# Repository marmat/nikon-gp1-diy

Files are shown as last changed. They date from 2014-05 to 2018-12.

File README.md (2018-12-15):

DIY GPS Module for Nikon DSLRs
==============================

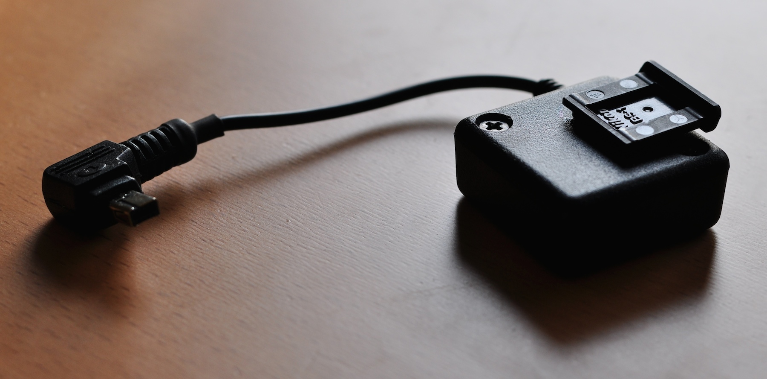
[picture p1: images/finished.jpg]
The finished device


Using a GPS Module, most modern Nikon DSLRs are able to automatically geotag
pictures right when taking them. Unfortunately, the official Nikon GP-1 is very
expensive (~200€). This project contains all necessary information to create a
low-cost module which works just as well. This DIY version costs around 30€
(40$).

- [Requirements](#requirements)
  - [Tools](#tools)
  - [Parts](#parts)
  - [Electronic Components](#electronic-components)
- [Building Instructions](#building-instructions)
- [Technical Details](#technical-details)
  - [Nikon GPS Port Specs](#nikon-gps-port-specs)
  - [Protocol](#protocol)
  - [Schematics](#schematics)
- [Images](#images)
- [Sources](#sources)

See also the [Building Log](BUILD.md).

Requirements
------------

### Tools

- Soldering Equipment
- Sharp knife to cut soft plastic
- A small dremel or similar to cut hard plastic
- Plastic Glue
- Screwdriver

### Parts

| Item | Description |
| --- | --- |
| Case | Hammond 1551NBK |
| PCB | Board layout available in [eagle](eagle/) folder. Either create your own if you have the equipment, visit your local [FabLab](http://en.wikipedia.org/wiki/Fablab) or let the PCB be created professionally (look for cheap companies in your region). |
| Cable & Connector | Can be taken from a cheap remote cable trigger. |

### Electronic Components

|  ID |  Item description | Part No. |  Size |
| --- | --- | --- | ----- |
| IC1 | GPS Module | Maestro A2235-H | |
| IC2 | Voltage Regulator | LP2985-33 | SOT23 |
| IC3 | Level Shifter | MAX3370 | 5SC70 |
| R1  | Resistor | 10 kOhm | 1206  |
| R2  | Resistor | 2.2 kOhm | 1206  |
| R3  | Resistor | 2.2 kOhm | 1206  |
| C1  | Capacitor | 10 nF | 0805  |
| C2  | Capacitor | 1 µF | 0805  |
| C3  | Capacitor | 2.2 µF | 0805  |

Building Instructions
---------------------

1. Disassemble the remote trigger. If the cable has only 3 wires, you will have
   to cut the connector in half and rewire them to pins 3, 4 and 7. Use plastic
   glue and a vice to put the two connector halves back together after rewiring.
   Before rewiring, you can optionally shorten the cable to your desired length.
   Make sure to preserve the cable protection on the side of the trigger. We
   will reuse it for our GPS module.
2. Solder all electronic components onto the the PCB. I have done this in the
   order from largest to smallest, but do whatever is most comfortable to you.
   You might also want to consider reflow soldering, especially for the GPS
   module. If you do regular soldering, feel free to keep the ground pads on the
   bottom of the GPS module unconnected. I have done so and it does not cause
   any issues.
3. (optional, recommended) Do an electrical check of the PCB using a Multimeter.
   Make sure no pads are connected that shouldn't be connected.
4. (optional) Attach a 5V power source to the board (pads P1 and P3). Attach an
   oscilloscope to P2. You should see a burst of data coming in at about 1Hz,
   otherwise the pin should have a high level (+5V).
5. The PCB will be placed inside the lid of the case. Optional: use glue to
   attach the PCB permanently.
6. Use a dremel to cut a slot into the case with the width of the cable. Check
   if the original cable protection fits into the slot and adjust if necessary.
7. Shorten the part of the cable which will be inside the case and solder the
   wires to pads P1-P3.
8. Assemble the case by using the supplied case screws.
9. Go outside and check if the device operates properly. **Note:** it might take
   a while for the first GPS fix. Make sure to have a good visibility to the
   sky.
10. (optional) Use plastic glue to attach a hot shoe protection cap to the lid
    of the case (such that the GPS antenna will face upward). This will allow
    for a secure mounting of the device on the camera.

Technical Details
-----------------

### Nikon GPS Port Specs

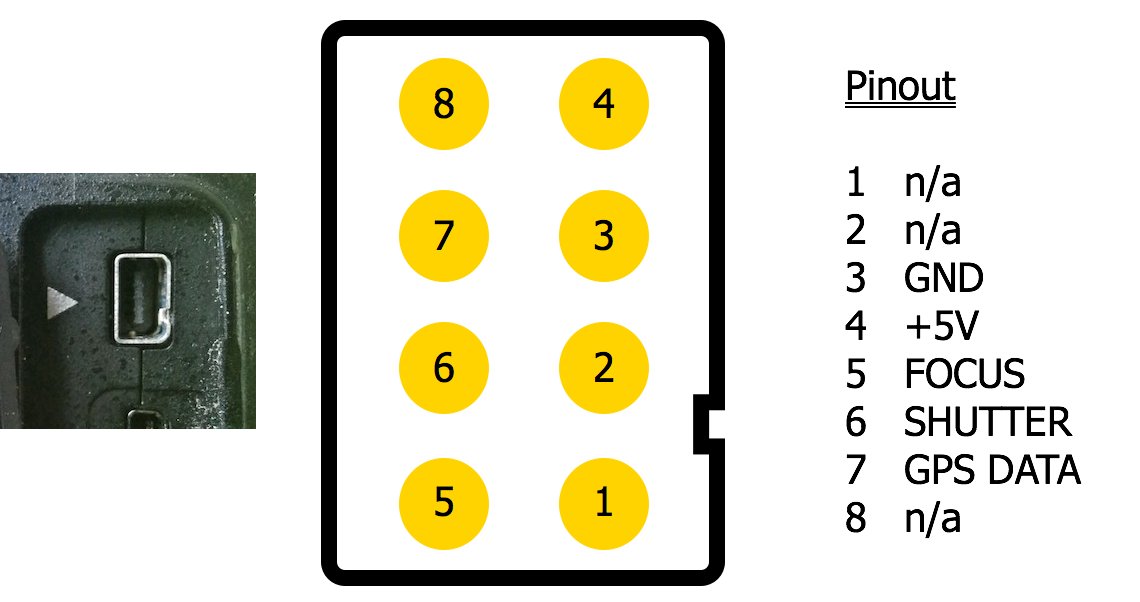
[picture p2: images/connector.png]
Connector


* Proprietary 8-pin connector,
  [pinout](http://pinoutsguide.com/DigitalCameras/nikon_d90_pinout.shtml)
* Operating voltage: 5V

### Protocol

The camera awaits NMEA-compliant messages over the GPS DATA pin. Data is
transmitted via UART with 4800 baud, no parity, 1 stop bit.

### Schematics

The schematics and PCB layout was created using Eagle. You can find all required
files in the [eagle](eagle/) subdirectory. Additionally, the folder
[eagle-lbr](eagle-lbr/) contains a library of custom made components which are
not part of the original Eagle libraries. Since the camera accepts raw NMEA
data, the circuit is extremely simple and does not require additional
controllers. The only difficulty is based in the operating voltage: the camera
uses 5V while the GPS module operates with 3.3V. Therefore a voltage regulator
and level shifter has been added to ensure correct levels on both sides.

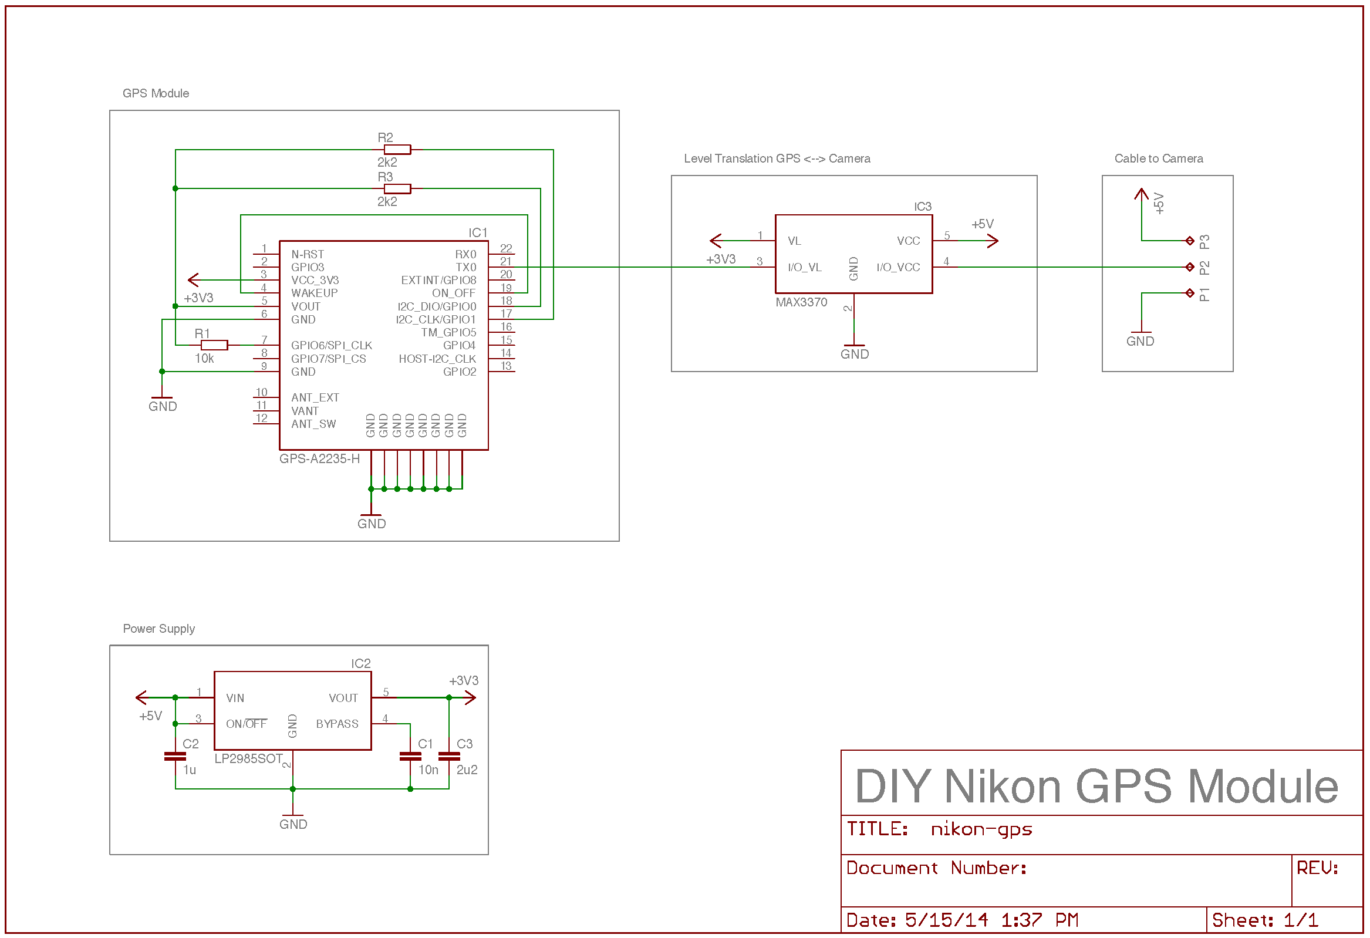
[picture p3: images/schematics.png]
Schematics


Images
------

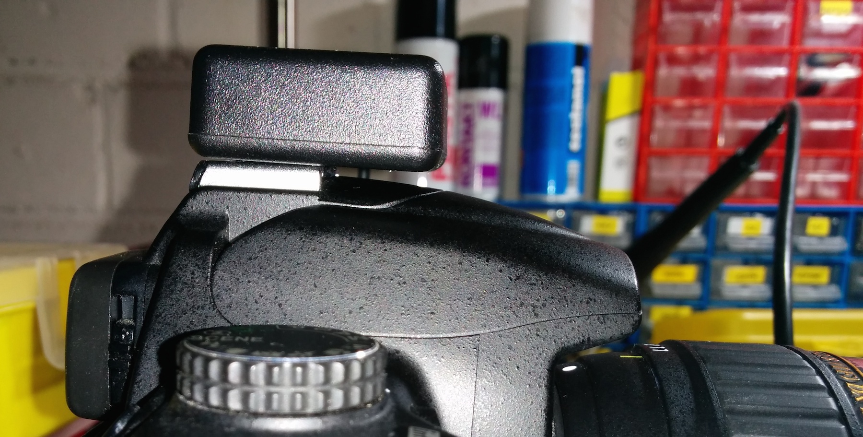
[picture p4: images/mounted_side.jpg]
Mounted on a camera

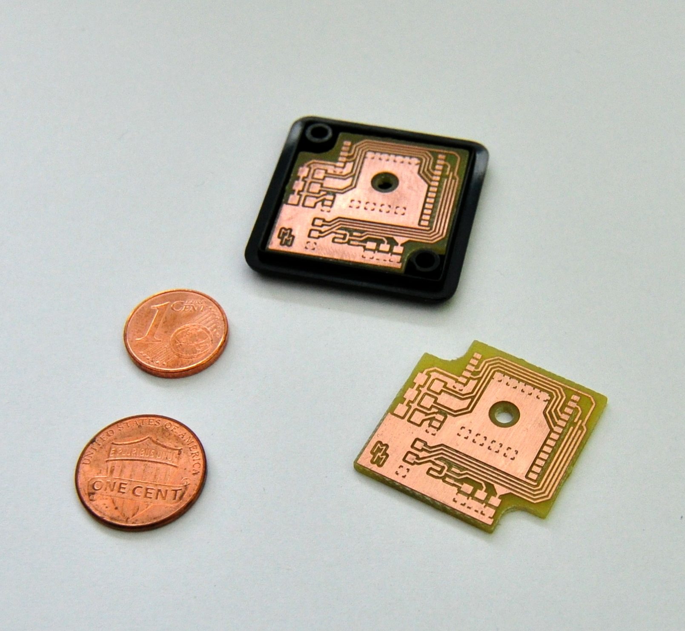
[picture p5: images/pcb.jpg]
The PCB

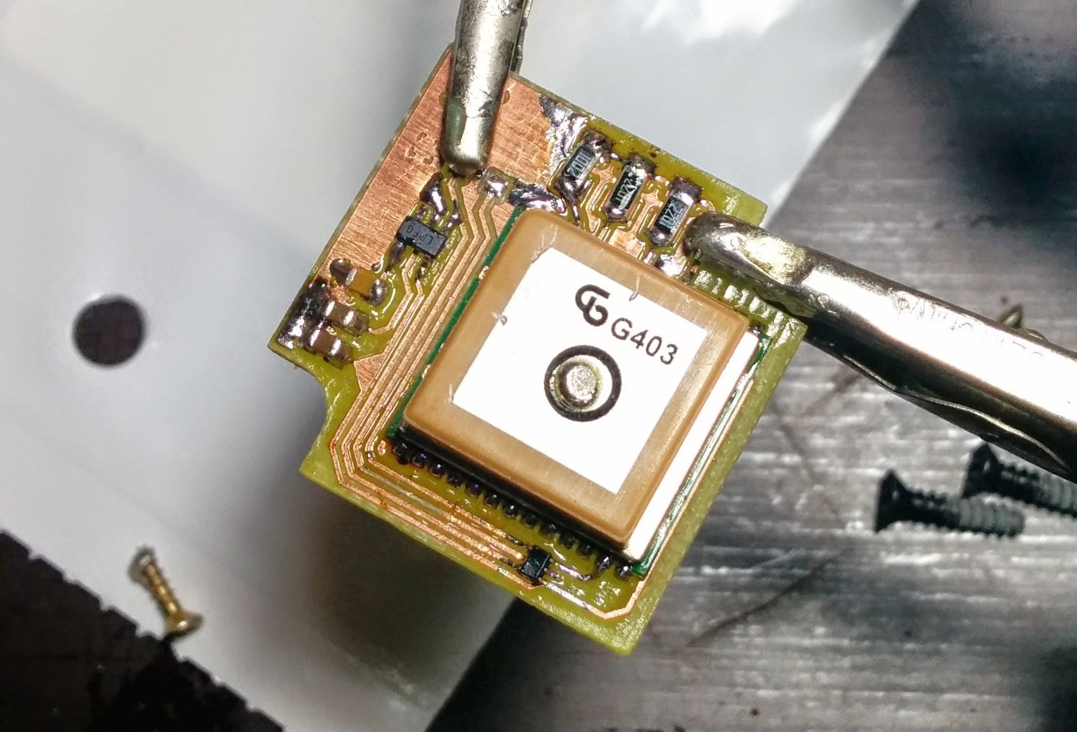
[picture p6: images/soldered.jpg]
The soldered circuit


Sources
-------

1. [Peter Miller Photography](http://www.petermillerphoto.com/nikongps/nikongps2.html)
2. [Homepage of Bálint Kis](http://www.k-i-s.org/index.php?item=13)
3. [Pinouts Guide](http://pinoutsguide.com/DigitalCameras/nikon_d90_pinout.shtml)

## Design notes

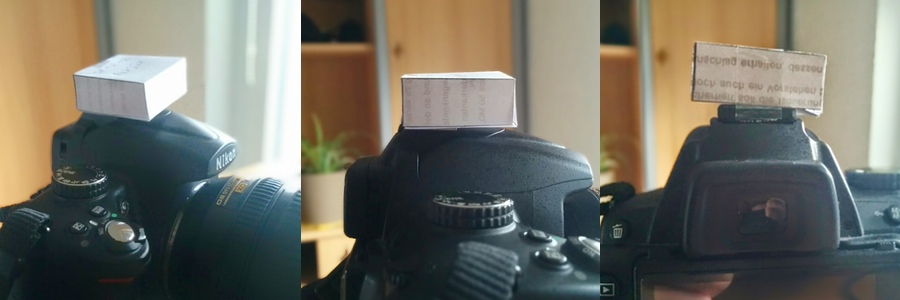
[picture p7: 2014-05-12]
images/paper_proto.jpg

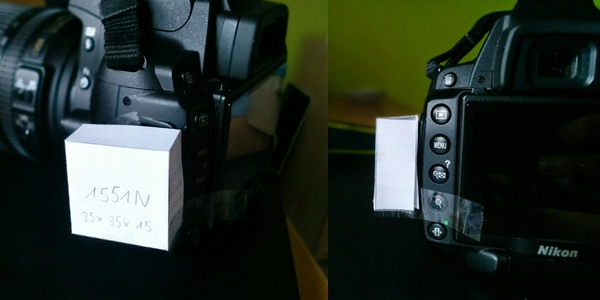
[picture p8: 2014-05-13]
images/paper_proto2.jpg

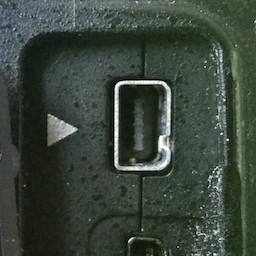
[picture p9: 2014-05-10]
images/connector.jpg

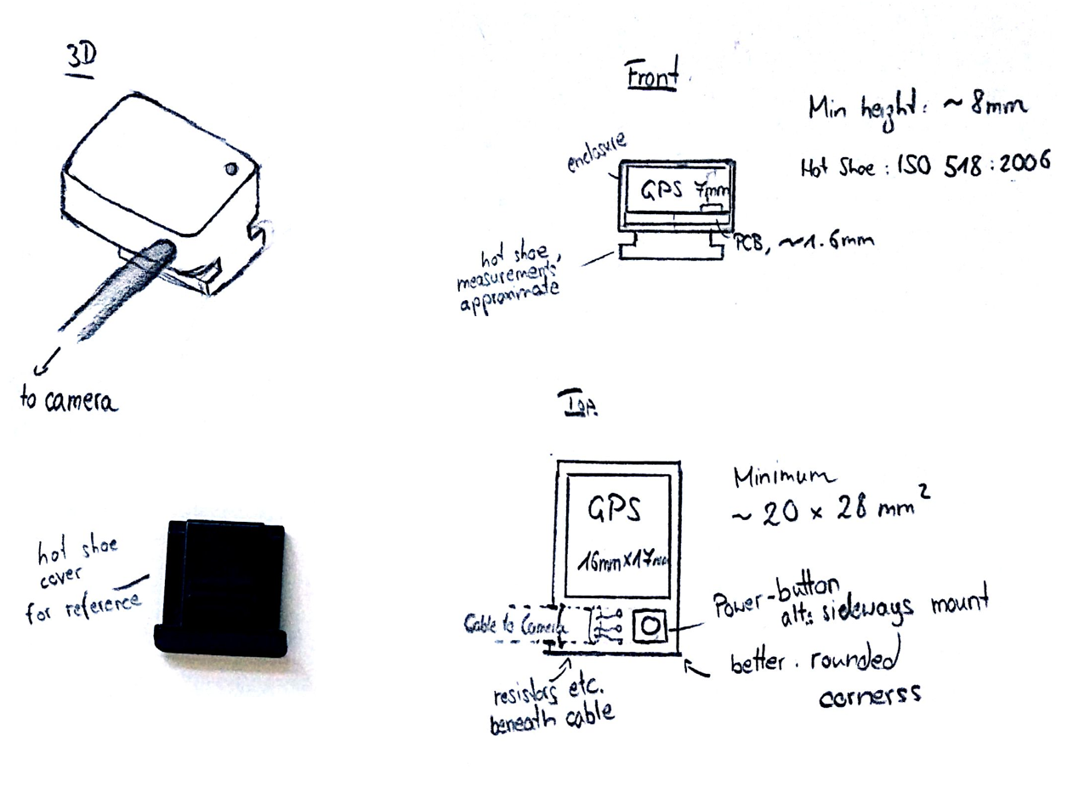
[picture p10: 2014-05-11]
images/sketch.png

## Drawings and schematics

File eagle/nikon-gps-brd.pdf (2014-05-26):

IC1

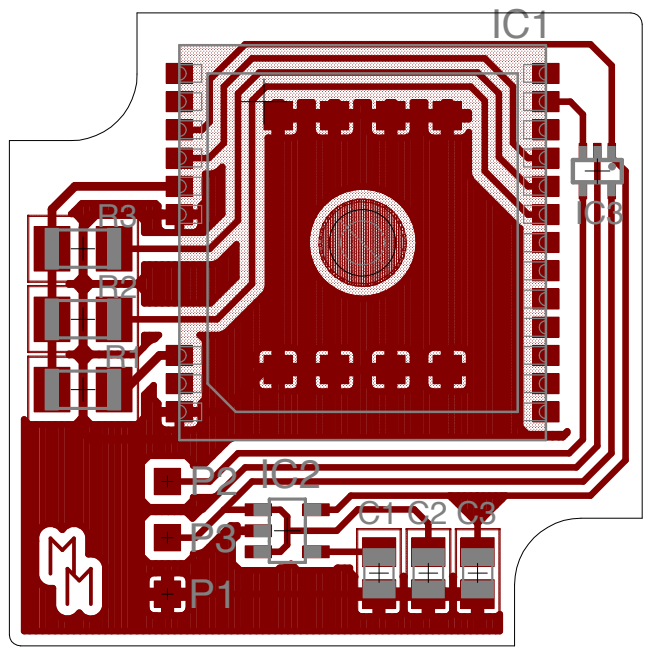
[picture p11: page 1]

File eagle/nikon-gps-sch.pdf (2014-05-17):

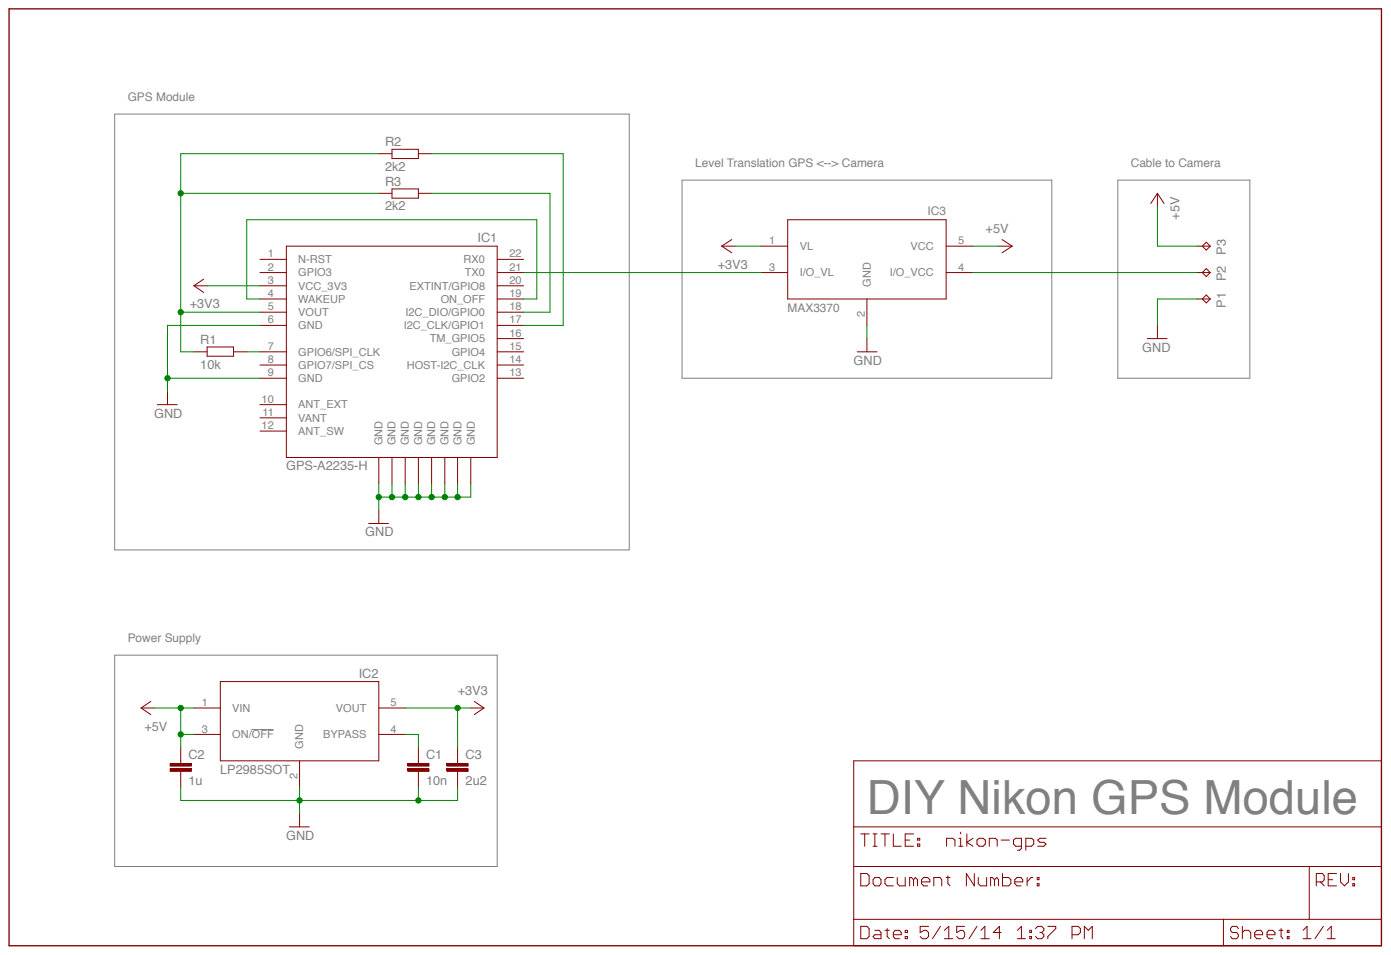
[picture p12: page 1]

DIY Nikon GPS Module

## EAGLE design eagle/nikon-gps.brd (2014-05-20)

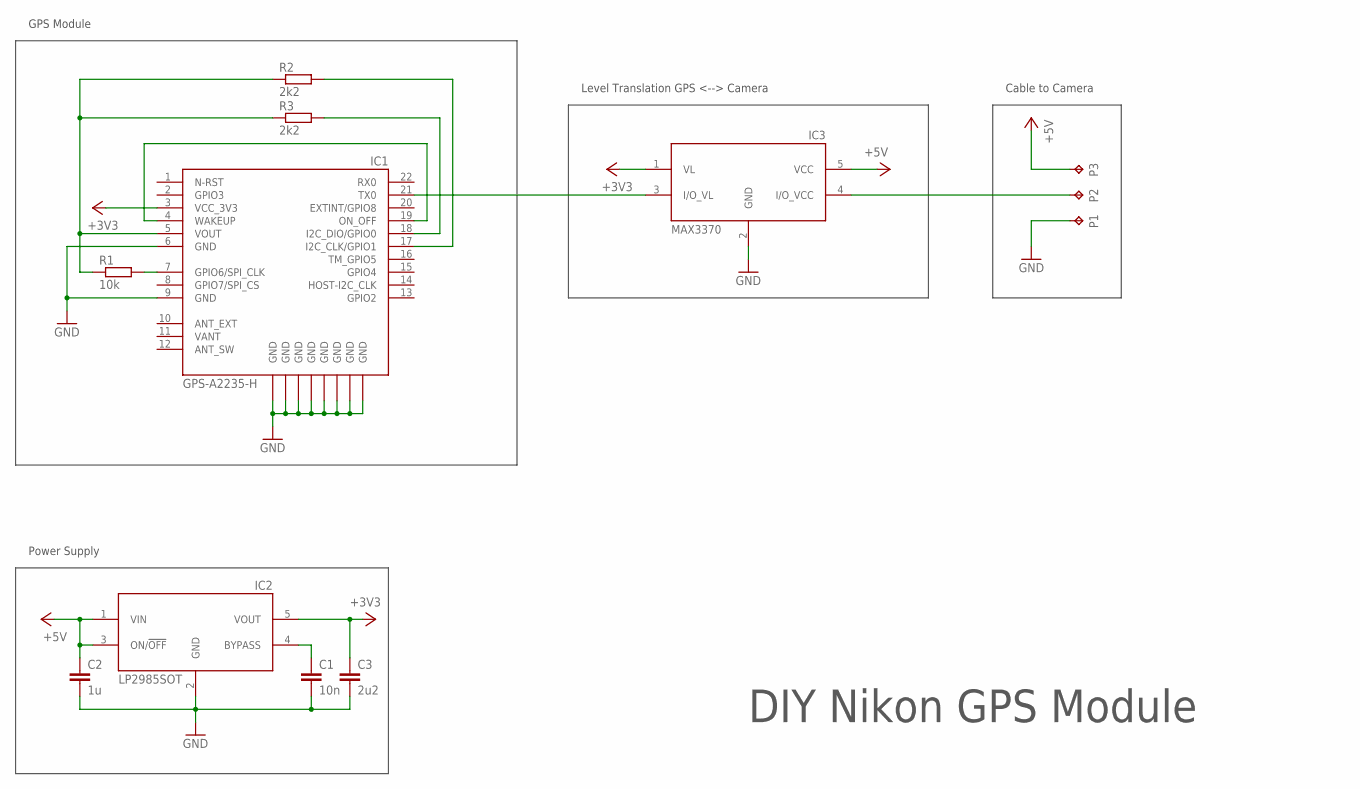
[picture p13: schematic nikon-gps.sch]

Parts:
C1: 10n; C0805
C2: 1u; C0805
C3: 2u2; C0805
IC1: GPS-A2235-H
IC2: LP2985SOT; SOT23-5L
IC3: MAX3370; SC70-5L
P1, P2, P3: TPTP12SQ; TP12SQ
R1: 10k; M1206
R2, R3: 2k2; M1206

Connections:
+3V3: C3.1, IC1.3 (VCC_3V3), IC2.5 (VOUT), IC3.1 (VL)
+5V: C2.1, IC2.1 (VIN), IC2.3 (ON/!OFF), IC3.5 (VCC), P3.TP
GND: C1.2, C2.2, C3.2, IC1.6 (GND), IC1.9 (GND), IC1.GND_PAD@1 (GND), IC1.GND_PAD@2 (GND), IC1.GND_PAD@3 (GND), IC1.GND_PAD@4 (GND), IC1.GND_PAD@5 (GND), IC1.GND_PAD@6 (GND), IC1.GND_PAD@7 (GND), IC1.GND_PAD@8 (GND), IC2.2 (GND), IC3.2 (GND), P1.TP
unnamed: C1.1, IC2.4 (BYPASS)
unnamed: IC1.21 (TX0), IC3.3 (I/O_VL)
unnamed: IC3.4 (I/O_VCC), P2.TP
unnamed: IC1.7 (GPIO6/SPI_CLK), R1.2
unnamed: IC1.18 (I2C_DIO/GPIO0), R3.2
unnamed: IC1.17 (I2C_CLK/GPIO1), R2.2
unnamed: IC1.4 (WAKEUP), IC1.19 (ON_OFF)
VANT: IC1.11 (VANT)
VOUT: IC1.5 (VOUT), R1.1, R2.1, R3.1

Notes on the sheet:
DIY Nikon GPS Module
Power Supply
Cable to Camera
Level Translation GPS <--> Camera
GPS Module

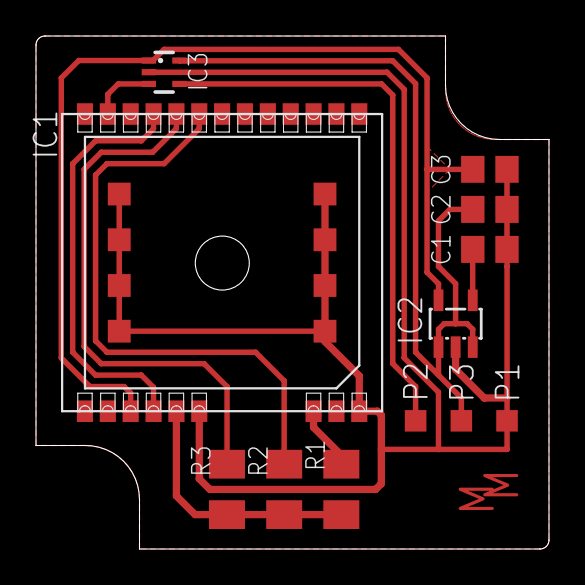
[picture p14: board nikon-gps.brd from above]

Board: 2 copper layers, 28.5 x 28.5 mm, 12 parts (0 on the bottom side), 11 nets.

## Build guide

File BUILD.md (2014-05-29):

Building Log
============

(sorted most recent first)

## 5/28/14 - Attaching a hot shoe cover

Using plastic glue and a thin sheet of plastic between the hot shoe cover and
the case, I have attached the device such that it easily slides in and out of
the hot shoe mount of DSLRs. This ensures a stable mount without any dangling
parts and good reception because the device sits on top of the camera, with the
GPS antenna facing straight toward the sky. With that, the GPS module is
finished and can be used in a practical setting!

The finished device
Mounted on a camera

## 5/27/14 - Assembling the Device

Soldering of the parts was easier than expected, even the small MAX3370 could be
soldered without too many issues. Before connecting the board to the camera, an
electrical check has been performed first (to make sure no pads are erroneously
shorted) and then a scope has been attached to the data output to make sure the
GPS module is operating normally. The device was powered by an external power
supply with 5.5V output. While only an analog scope was available, it was
sufficient to see the NMEA data bursts coming in with a regular interval (image
links to youtube):

Functional Test (http://www.youtube.com/watch?v=M3ckGG12SQM)

The board was then placed inside the case and connected to the camera. It works!

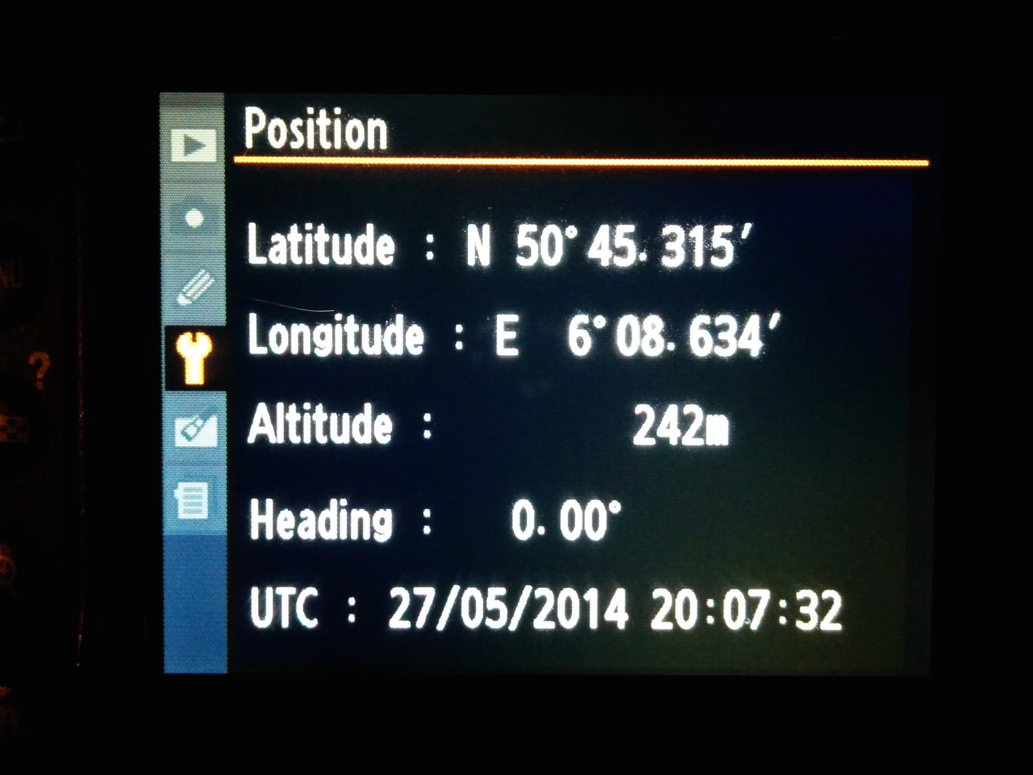
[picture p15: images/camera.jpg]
Camera Display


After waiting for about 30 - 60 seconds for the first GPS fix, the camera is
able to show the location and photographs are automatically tagged with said
location. The last step to complete the project is to connect the case with a
hot shoe cap such that the module can be attached securely to the camera body.

## 5/27/14 - Milling the PCB

During an appointment at my local [FabLab](https://hci.rwth-aachen.de/fablab), I
could use a mill to create a prototype of the PCB. In contrast to
photoengraving, milling a small board is much faster and cleaner because no
chemicals have to be used for etching the copper. Milling the 28.5mm x 28.5mm
board took about 10-15 minutes:

PCB

With the PCB being the last missing component, we can now assemble the device,
check if it operates normally when supplying current and finally try to connect
it to the camera. Soldering the MAX3370 level shifter will probably be the most
complicated part as it comes in a very small package (0.65mm pin distance).

## 5/20/14 - Received the parts

While the PCB is not done yet, I could do first experiments with the Hammond
case. Due to the limited space, I will change the PCB layout a bit and mount the
PCB upside down (i.e. the PCB will be attached to the lid). Advantages:

- No problem with missing height anymore (with regular mounting ~0.7mm are
  missing)
- Case screws will be on the bottom, thus practically invisible
- No need for screw holes on PCB itself, making much more space available for
  routing

Unfortunately, the PCB has to trimmed by about a millimeter on each side. This
should not cause any problems with the current layout, though. The cable will
stick out to the side. Using the original cable protection from the remote
trigger, we have a very clean looking connection:

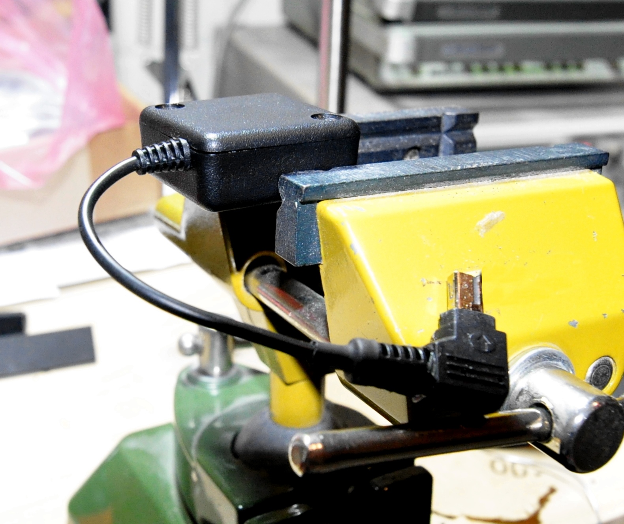
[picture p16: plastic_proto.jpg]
Plastic Prototype


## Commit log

2014-05-11 Adding A2235-H device, symbol & package to selfmade lib.
    Updating partlist according to more recent A2235-H user manual
    recommendations.
2014-05-12 Updating part list with new findings. Adding paper prototype.
    Adding notes about switch placement and interior dimensions
    of 1551NBK.
2014-05-12 Adding PTS645V device + package + symbol to selfmade library.
2014-05-13 Adding variant of the paper prototype.
2014-05-13 Update: switch not needed according to latest user manual of A2235H.
    Adding MAX3370 to selfmade library.
2014-05-13 Adding initial schematics and board layout.
    [nikon-gps.brd, nikon-gps.sch]
2014-05-14 First stab at a PCB layout.
    The part placement might still be optimized, esp. if we consider adding
    a Status-LED.
    [nikon-gps.brd, nikon-gps.sch]
2014-05-15 Adding missing capacitors for LP2985 voltage regulator.
    [nikon-gps.brd, nikon-gps.sch]
2014-05-16 Updating README to reflect current project status.
2014-05-16 Updating Partlist to match Schematics.
    Updating most of the prices to match Mouser price + 19% VAT.
    Adding note regarding remote trigger.
2014-05-16 Slightly adjusting placement of cable soldering pads.
    [nikon-gps.brd]
2014-05-17 Adding PDFs of PCB and Schematic for easier preview on GitHub.
    [nikon-gps.brd]
2014-05-20 Updating PCB to fit inside the lid (now 28.5mm x 28.5mm).
    [nikon-gps.brd]
2014-05-26 Creating files for PCB mill as per hci.rwth-aachen.de/mill instructions.
2014-05-26 Updating pdf preview of board layout.
